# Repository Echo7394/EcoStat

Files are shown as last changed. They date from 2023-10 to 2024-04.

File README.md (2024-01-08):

# EcoStat
<p>
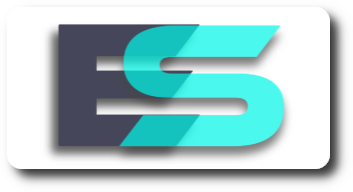
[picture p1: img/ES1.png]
  

EcoStat is an open-source thermostat control system built using the Seed Studio Xiao ESP32C3 microcontroller.
It allows you to control heating, cooling, and fan systems using physical buttons and a web-based interface. 
Additionally, it displays temperature and humidity information on an OLED screen. The goal of this project was
to create a cheap, energy saving, open source smart thermostat that doesnt spy on you. So, finally and most 
importantly, EcoStat does not use or collect any kind of telemetry data, at ALL.

**V2 Supports Heating & Cooling automatically with multiple relays and all additional features.
V1 only supports minimal features with two relays, it can be used for cooling as well. V1 requires you 
to manually move the wire from heating to cooling seasonally, V1 simply offers a cheaper
version of the project.**

I put a lot of soul into this project, and more importantly the desire to keep it free, open source, and unintrusive.
So if you enjoy it, please consider buying me a coffee! <a href="https://cash.app/$seripsirhc">**Donate :)**</a>

</p>
<p float="left">
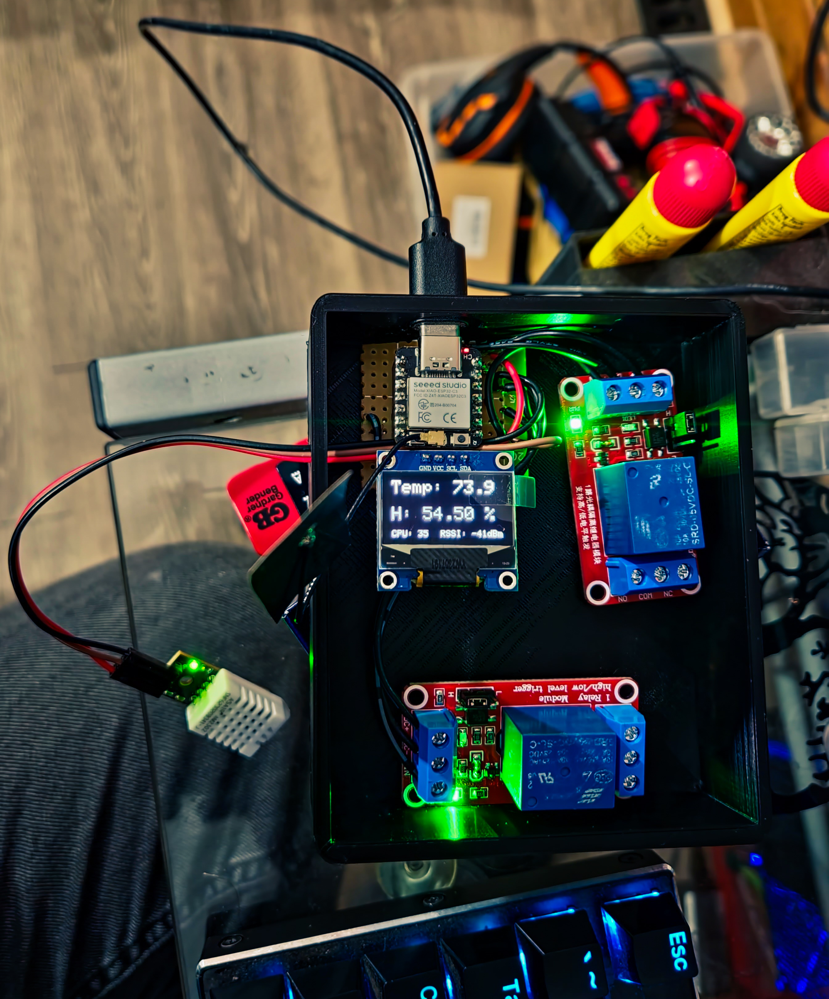
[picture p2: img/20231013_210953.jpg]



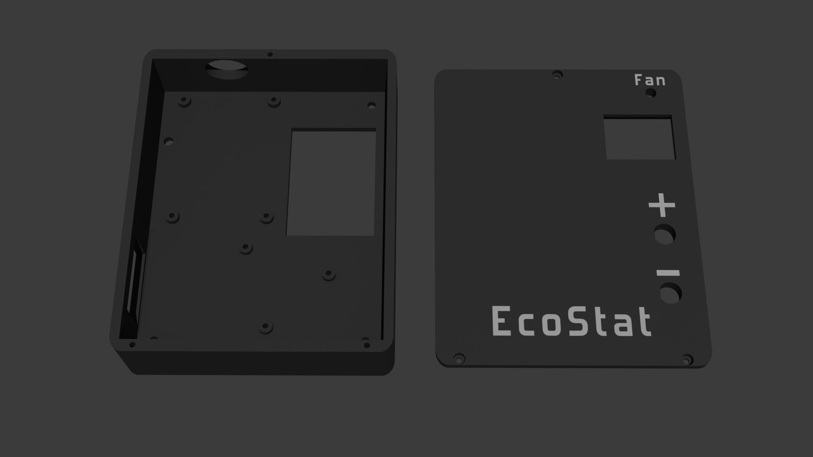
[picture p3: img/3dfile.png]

</p>

**Features:**
<ul>
<p>
<li>Energy efficient HVAC control using timing based logic and hysteresis.</li>
<li>Web-based interface for remote control.</li>
<li>Real-time temperature and humidity display.</li>
<li>Physical buttons for normal offline control.</li>
<li>Mode selection (Heating, Cooling, Off).</li>
<li>Independent Fan control (circulating fan).</li>
<li>Wi-Fi setup using a captive portal.</li>
</p>
</ul>

<hr>

**Hardware Requirements (Total cost approx $45)**

**-Seeed Studio Xiao ESP32C3**

**-Any 128x64 SSD1306 I2C OLED Screen**

**-Two or Three 5V One Channel Relay Modules, I used "HiLetgo 2pcs 5V One Channel Relay Module Relay Switch with OPTO Isolation High Low Level Trigger" from Amazon**
  
**-A DHT22 Sensor, I used a "Gowoops 2pcs DHT22/AM2302 Digital Humidity and Temperature Sensor Module" from Amazon**
  
**-Micro Momentary Button, I used a 4 pin type, you can use anything that fits the mounting hole (6mm or less).**
<hr>

**Software Dependencies**
<p>
	
khoih-prog/ESP_WifiManager@^1.12.1
	
adafruit/DHT sensor library@^1.4.4

adafruit/Adafruit SSD1306@^2.5.7

https://github.com/me-no-dev/ESPAsyncWebServer.git (Must change AsyncWebSocket.cpp: "return IPAddress(0U)"; to "return IPAddress((uint32_t)0U)" )

adafruit/Adafruit Unified Sensor@^1.1.13

</p>
<hr>

**Configuration**
<ul>
<li>Set your desired username and password for web-based authentication using http_username and http_password (default is blank user, with pass: 13371337).</li>
<li>Connect the relay modules and physical buttons to the specified pins as defined in the code.</li>
<li>Install neccessary libraries</li>
<li>Compile/Build</li>
<li>Upload the code to your ESP32C3 device.</li>
<li>Uncomment Serial.begin & Open the serial monitor for debugging (optional).</li>
<li>Access the EcoStat web interface by connecting to the Wi-Fi network "EcoStat-Setup" and visiting the IP address assigned to your device.</li>
<li>Use the web interface to control heating, cooling, fan, and set the target temperature.</li>
</ul>
<hr>

**Button Controls**
<ul>
<li>BUTTON_FAN: Toggle the fan on and off.</li>
<li>BUTTON_MODE: Switch between Heating, Cooling, and Off modes.</li>
<li>BUTTON_PIN0 and BUTTON_PIN1: Increase and decrease the target temperature.</li>
</ul>
<hr>
<p>
The screen displays Temperature, Humidity, MCU Temp, and Wifi Signal Strength.
Buttons toggle temperature up & down by one degree at a time.
The "Heat" relay does not trigger until the current temperature is 2 degrees lower than the target temperature and it has been more than 120 seconds to prevent excessive
toggling and save energy / gas / LP.
The web page also provides the option to trigger the "Fan" relay seperately for air circulation without climate control.</p>
<hr>

Detailed description of the goals of this project and a summary of exactly what the code does:

1. It includes various libraries for Wi-Fi management, sensor readings (DHT22), OLED display control, and web server functionality.
2. It defines pins and addresses for the OLED display, DHT22 sensor, buttons, and relays.
3. It sets up Wi-Fi using the ESPAsyncWiFiManager library, allowing users to configure the network credentials via a captive portal.
4. It initializes the OLED display, creates a web server on port 80, and defines routes for controlling the thermostat remotely.
5. It handles HTTP GET requests for increasing/decreasing the target temperature, turning the fan on/off, and changing the operating mode (heating, cooling, or off).
6. It defines functions for reading the temperature, changing the mode, and updating the OLED display with current status.
7. It sets up interrupt handlers for physical buttons to change the target temperature, mode, or fan status.
8. The main loop continuously reads temperature and humidity from the DHT22 sensor and updates the OLED display.
9. Depending on the operating mode (heating or cooling), it controls relays to turn on/off the heating or cooling system to maintain the desired temperature.

Overall, this code creates a thermostat system with remote control capabilities, allowing users to adjust the target temperature, mode, and fan status through a web interface. It also displays current temperature and humidity on an OLED screen. The system can operate in heating or cooling mode based on the target temperature, and it provides visual feedback on the OLED screen for the user. The physical buttons provide additional control and feedback for users without accessing the web interface. No unnecessary data is collected or transmitted by the device, and no personal data is transmitted outside of your LAN.

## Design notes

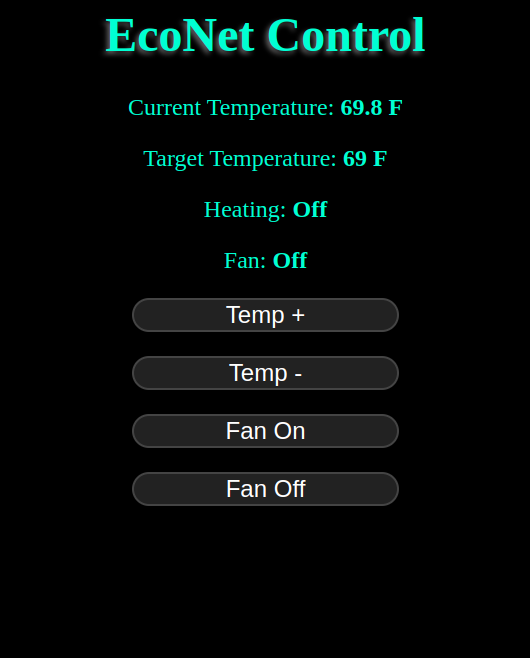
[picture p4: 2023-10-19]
img/EcoNet.png

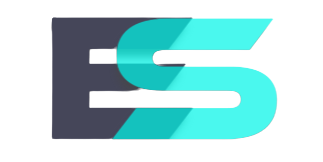
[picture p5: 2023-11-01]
img/blah22-removebg-preview.png

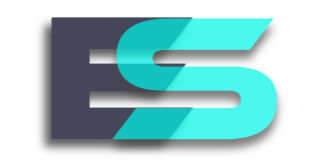
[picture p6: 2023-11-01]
img/blah22.png

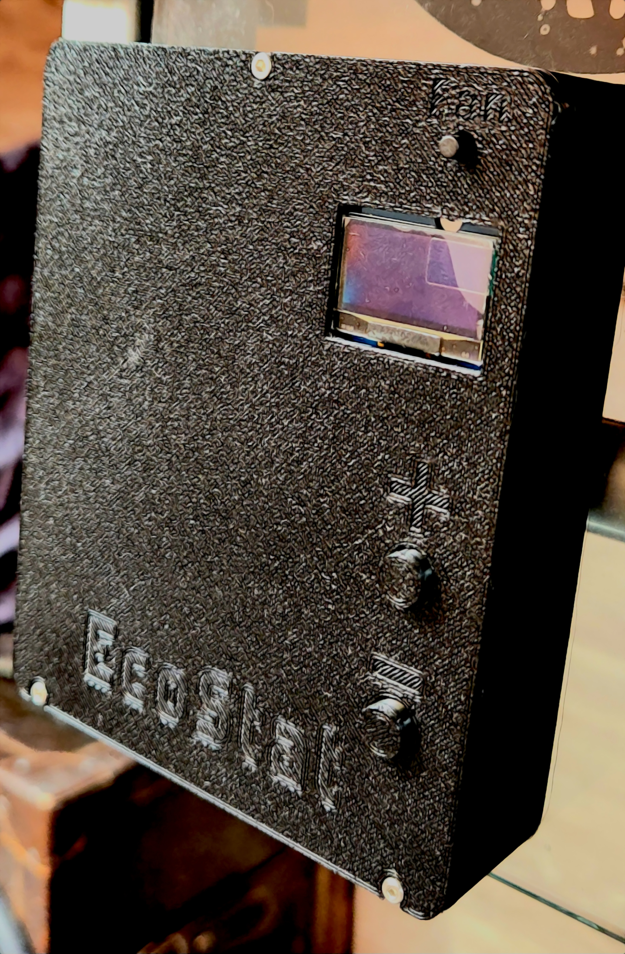
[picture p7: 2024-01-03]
img/esupdate.jpg

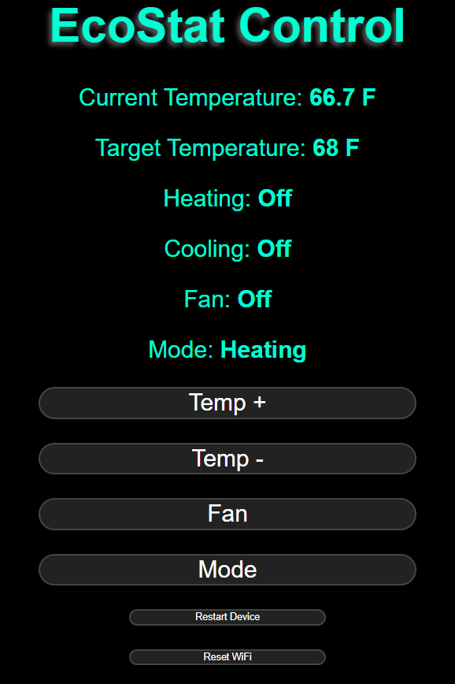
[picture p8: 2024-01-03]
img/esss.png

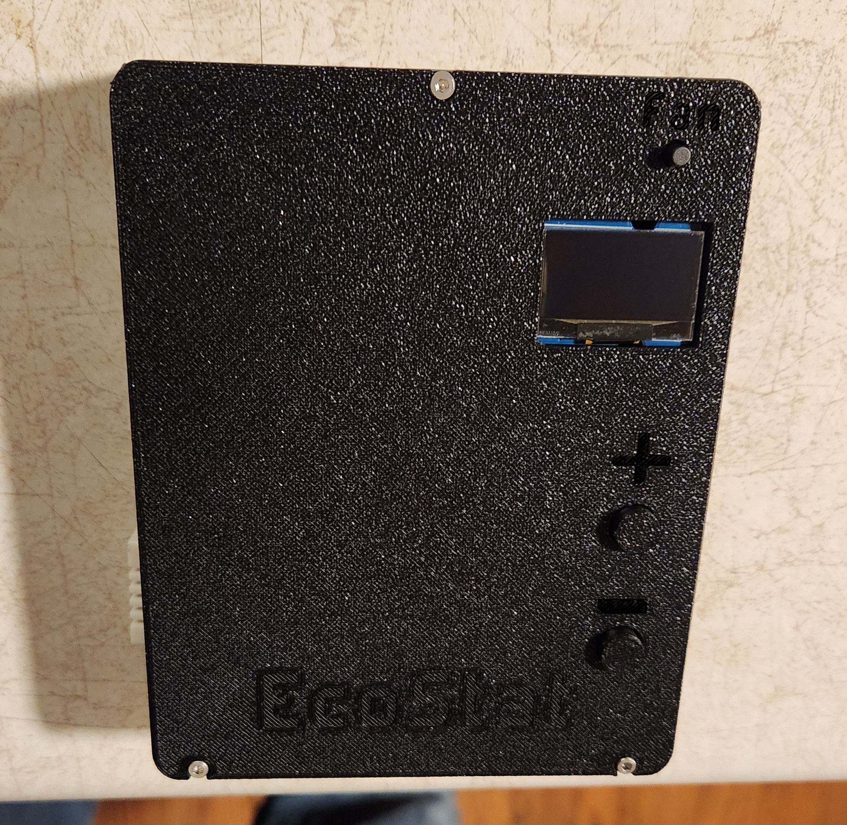
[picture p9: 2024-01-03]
img/ESN1.jpg

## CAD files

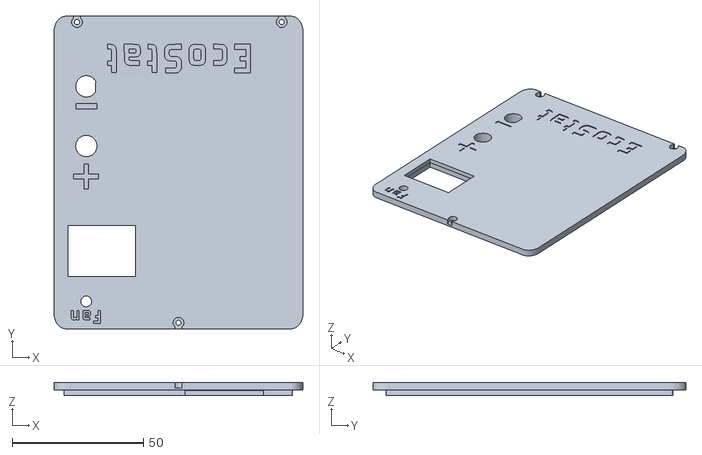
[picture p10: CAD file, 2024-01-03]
Case_Models/EcoStatV2-ecostatlid.stl
94.7 x 118.9 x 5.11

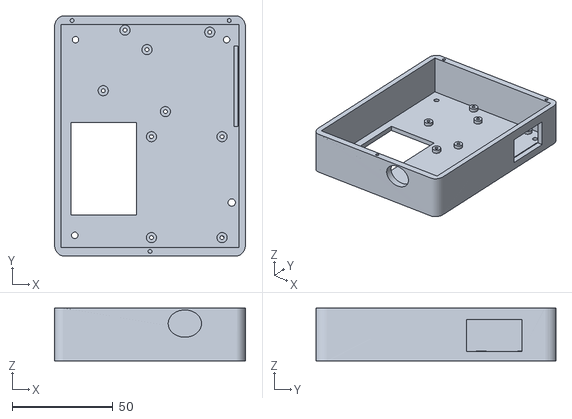
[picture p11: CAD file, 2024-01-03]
Case_Models/EcoStatV2-ecostatcase.stl
94.7 x 118.9 x 26.2

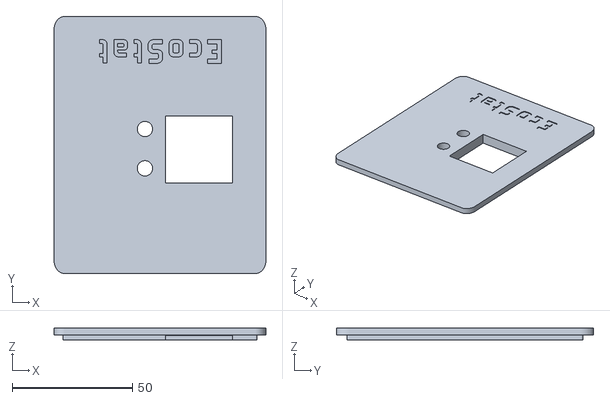
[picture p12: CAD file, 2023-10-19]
Case_Models/microstatlid.stl
88.2 x 107.0 x 5.11

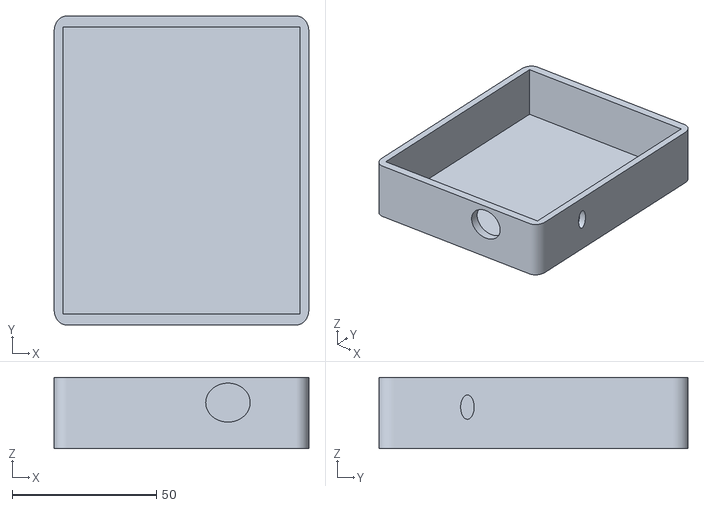
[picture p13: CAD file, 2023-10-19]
Case_Models/microstatcase.stl
88.2 x 107.0 x 24.8

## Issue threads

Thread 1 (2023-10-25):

Seeed Studio Contributor Program

MatthewJeffson, 2023-10-25:
Hi Chris!
It is nice to meet you. I'm Matthew from Seeed Studio and I'm responsible for our little program called "[Contributor Program](https://github.com/orgs/Seeed-Studio/projects/6/views/1?pane=issue&itemId=30957479)". Your project here is so interested and very attached to our recent theme: Home Assistant.

Hence, may I ask if you are interested redoing this project, by using our products(Grove modules)? And let it be able to be controlled and viewed the data on Home Assistant devices?
Here is a reference: [XIAO ESP32C3 connecting with Home Assistant via ESPHome(all ports supported)](https://wiki.seeedstudio.com/XIAO-ESP32C3-for-ESPHome-Support/)

A working demo and wiki contents will be fine. I will create an assignment and assigned to you in our program.
Really looking forward our operation.
Best Regards,
Matthew

Echo7394, 2023-10-25:
I would be extremely happy to create a version of EcoStat that supports Home Assistant using Grove modules. Would you or anyone at Seeed Studio be willing to provide demo hardware (a Xiao ESP32C3 or S3 and Grove Modules) to use for testing and development as well as to create a demo video with?

MatthewJeffson, 2023-10-26:
Hello! Sure I can and happy to ask some hardware for you :)
May we contact with email so we can discuss privately.
Best Regards,
Matthew

Echo7394, 2023-10-26:
Absolutely, my E-Mail is echo7394@protonmail.com

Closed 2024-01-03.

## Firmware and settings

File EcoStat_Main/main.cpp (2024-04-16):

/**************************************************************************************
░█▀▀░█▀▀░█▀█░█▀▀░▀█▀░█▀█░▀█▀     													  
░█▀▀░█░░░█░█░▀▀█░░█░░█▀█░░█░                                                          
░▀▀▀░▀▀▀░▀▀▀░▀▀▀░░▀░░▀░▀░░▀░                                                          
GNU GENERAL PUBLIC LICENSE V3.0                                                       
Made by Echo7394                             
This is the most updated version of the code!!
**************************************************************************************/
#include <ArduinoOTA.h>
#include <DNSServer.h>
#include <ESP_WiFiManager.h>
#include <Wire.h>
#include <DHT.h>
#include <Adafruit_SSD1306.h>
#include <esp_system.h>
#include <ESPAsyncWebServer.h>

#define SCREEN_WIDTH 128
#define SCREEN_HEIGHT 64
#define OLED_RESET -1        // Reset pin (if used)
#define SCREEN_ADDRESS 0x3C  // I2C address for the OLED

Adafruit_SSD1306 display(SCREEN_WIDTH, SCREEN_HEIGHT, &Wire, OLED_RESET);

#define DHT_PIN 20  // Sets the data pin for the DHT22
DHT dht(DHT_PIN, DHT22);

#define BUTTON_FAN 4   // Button to switch fan on and off manually
#define BUTTON_MODE 3  // Button to select "Heating / Cooling / Off"
#define BUTTON_PIN0 8  // Button to raise tempSet
#define BUTTON_PIN1 2  // Button to lower tempSet

#define buzzerPin 5   // trigger pin for piezo buzzer
#define RELAY_PIN 10   // trigger pin for "Heat" relay
#define RELAY_PIN0 5   // trigger pin for "Cooling" relay
#define RELAY_PIN1 21  // trigger pin for "Fan" relay

String ssid = "blank";      // Will store the Wi-Fi SSID from the captive portal
String password = "blank";  // Will store the Wi-Fi password

//IPAddress localIP(192, 168, 0, 201); //Uncomment to set a Static IP for EcoStat
//IPAddress gateway(192, 168, 0, 1);
//IPAddress subnet(255, 255, 255, 0);

AsyncWebServer server(80);  // Web server to port 80 TCP

int tempSet = 68;                        // Initial target temperature in degrees Fahrenheit
const char *http_username = "";          // Change to your desired username
const char *http_password = "199312";  // Change to your desired password

unsigned long lastDebounceTime = 0;       // Momentary switches like to be bouncy
unsigned long debounceDelay = 300;       // These variables will take care of that later
unsigned long modeStatusLastUpdated = 0;  // will be used for timing of displayModeStatus

bool heatingOn = false;  // heating status, starts as false since RELAY_PIN typically starts LOW
bool coolingOn = false;  // cooling status
bool fanisOn = false;    // same as above but for.... the fan relay

bool wifiCredentialsEntered = false;

unsigned long lastDHTPollTime = 0;
const unsigned long dhtPollInterval = 6000;

float celsiusToFahrenheit(float celsius) {  //Converts Celsius to Fahrenheit
  return (celsius * 9.0 / 5.0) + 32.0;
}

int mode = 0;  // 0 for off, 1 for heating, 2 for cooling

void changeMode() {
  mode = (mode + 1) % 3;  // Cycle through modes: 0 -> 1 -> 2 -> 0
  // Turn off heating and cooling when switching modes
  digitalWrite(RELAY_PIN, LOW);
  digitalWrite(RELAY_PIN0, LOW);
}

void displayTempSet(int tempSet) {  // This function gets flashed briefly on the OLED
  display.clearDisplay();           // when the target temp "tempSet" is changed
  display.setTextSize(2);
  display.setTextColor(SSD1306_WHITE);
  display.setCursor(0, 20);
  display.print(F("Target: "));
  display.print(tempSet);
  display.display();
}

void displayFanStatus() {  // Gets flashed to the OLED whenever fanisOn changes
  display.clearDisplay();
  display.setTextSize(2);
  display.setTextColor(SSD1306_WHITE);
  display.setCursor(0, 20);
  if (fanisOn == true) {
    display.print(F("Fan: On"));
  } else {
    display.print(F("Fan: Off"));
  }
  display.display();
}

String modeStatus = "Off";
int modeFan = 0;

void switchFan() {
  modeFan = (modeFan + 1) % 2; // Cycle fan state 0 -> 1 -> 0
  digitalWrite(RELAY_PIN1, modeFan == 1); // Turn on the fan relay when modeFan is 1
  fanisOn = (modeFan == 1);
}

void displayModeStatus(String modeStatus) {  // Gets flashed to the OLED whenever modeStatus changes
  display.clearDisplay();
  display.setTextSize(2);
  display.setTextColor(SSD1306_WHITE);
  display.setCursor(40, 10);
  display.print(F("Mode: "));
  display.setCursor(25,30);
  display.print(modeStatus);
  display.display();

  // Record the time when modeStatus is updated for use later
  modeStatusLastUpdated = millis();
}

void playTone(float frequency, int duration) {
  tone(buzzerPin, frequency);
  delay(duration);
  noTone(buzzerPin);
  delay(100);  // pause between tones
}

// setup function for BUTTON_MODE to increment the value of changeMode
void buttonmodePressed() {
  if (millis() - lastDebounceTime > debounceDelay) {
    changeMode();
    lastDebounceTime = millis();
  }
}

void button0Pressed() {
  if (millis() - lastDebounceTime > debounceDelay) {  // Fancy debounce stuff to make sure a button press = just 1 press
    tempSet += 1;                                     // Increase the target temperature by 1 degree
    lastDebounceTime = millis();
  }
}

void button1Pressed() {
  if (millis() - lastDebounceTime > debounceDelay) {
    tempSet -= 1;  // Increase the target temperature by 1 degree
    lastDebounceTime = millis();
  }
}

void buttonfanPressed() {
  if (millis() - lastDebounceTime > debounceDelay) {
  switchFan();
  lastDebounceTime = millis();
  }
}

void setup() {
  bool setCpuFrequencyMhz(80); // slowwww the CPU frequency down for stability and power consumption
//Serial.begin(115200);  // uncomment this if you need serial output for debugging
  delay(3000);           // Delay because i've heard setup can get skipped sometimes
                         // Do not know if thats true so this may not be neccessary

   playTone(700, 150);
   playTone(1000, 150);

  // Initialize the OLED screen
  if (!display.begin(SSD1306_SWITCHCAPVCC, SCREEN_ADDRESS)) {
    Serial.println(F("SSD1306 allocation failed"));
    for (;;)
      ;
  }

  display.setTextWrap(true);
  display.clearDisplay();  // This just ensures that we start with a clear display
  display.display();       // on the SSD1306 screen

  pinMode(RELAY_PIN, OUTPUT);
  pinMode(RELAY_PIN0, OUTPUT);
  pinMode(RELAY_PIN1, OUTPUT);   // Set Relay trigger pins as outputs, because they are.
  digitalWrite(RELAY_PIN, LOW);  // Ensure the relay is initially off
  digitalWrite(RELAY_PIN0, LOW);
  digitalWrite(RELAY_PIN1, LOW);
  pinMode(BUTTON_PIN0, INPUT_PULLUP);  // Gotta use a pullup for buttons because otherwise
  pinMode(BUTTON_PIN1, INPUT_PULLUP);  // Erwins Cats are going to get involved
  pinMode(BUTTON_FAN, INPUT_PULLUP);

  // display a notification to SSD1306 Screen for user setup if WiFi not attached to SSID
  ESP_WiFiManager wifiManager("EcoStatSetup");
  Serial.println("Waiting for WiFi credentials...");
  display.clearDisplay();
  display.setTextSize(1);
  display.setTextColor(SSD1306_WHITE);
  display.setCursor(15, 0);
  display.print("Connect to WiFi:");
  display.setCursor(28, 15);
  display.print("EcoStatSetup");
  display.setCursor(17, 40);
  display.print("In Your Browser");
  display.setCursor(10, 55);
  display.print("Enter: 192.168.4.1");
  display.display();
  Serial.println(wifiManager.getStoredWiFiPass());
  wifiManager.autoConnect("EcoStatSetup");  // Start a captive portal for the user to enter WiFi Credentials
  ssid = wifiManager.getStoredWiFiSSID();
  password = wifiManager.getStoredWiFiPass();
  wifiManager.setConfigPortalTimeout(300);  // Setup portal timeout in seconds, in case user doesnt setup WiFi
  WiFi.mode(WIFI_STA);

  // Connect to Wi-Fi
  WiFi.begin(ssid, password);
  while (WiFi.status() != WL_CONNECTED) {
    Serial.println("Connecting to WiFi...");
    display.clearDisplay();
    display.setTextSize(2);
    display.setTextColor(SSD1306_WHITE);
    display.setCursor(40, 10);
    display.print(F("WiFi"));  // display to SSD1306
    display.setCursor(5, 30);
    display.print(F("Connecting"));
    display.display();
    delay(1000);
  }
  Serial.println("Connected to WiFi");
  display.clearDisplay();
  display.setTextSize(2);
  display.setTextColor(SSD1306_WHITE);
  display.setCursor(40, 10);
  display.print(F("WiFi"));  // display to SSD1306
  display.setCursor(10, 30);
  display.print(F("Connected"));
  display.display();
  delay(3000);

  ArduinoOTA.begin();
  ArduinoOTA.setHostname("ESP32C3");
  ArduinoOTA.setPassword("ESP32C3");
  dht.begin();

  // Serve a webpage to control features remotely,
  // also added password protection so that you can access it outside of your home LAN
  server.on("/", HTTP_GET, [](AsyncWebServerRequest *request) {
    if (!request->authenticate(http_username, http_password)) {
      return request->requestAuthentication();
    }
    float temperatureC = dht.readTemperature();
    float temperatureF = celsiusToFahrenheit(temperatureC);
    String heatingStatus = heatingOn ? "On" : "Off";  // Determine the state of heatingOn and assign it to heating Status with a variable string
    String fanStatus = fanisOn ? "On" : "Off";        // Same thing but you know... the fan
    String coolingStatus = coolingOn ? "On" : "Off";  // yep
    
    String html = R"webServe(
    <!doctype html>
    <html>
    <body style='text-align: center;font-size: 24px;background-color: #000;color: #00FFD3;@import url('https://fonts.googleapis.com/css2?family=Roboto:wght@300;400;500;900&display=swap');'>
      <head>
        <meta name='viewport' content='width=device-width, initial-scale=1.0'>
        <meta http-equiv='refresh' content='8'>
      </head>
      <h1 style='margin-top: -8px; color: #00FFD3;text-shadow: -3px 3px 5px #5C5C5C;'>EcoStat Control</h1>
      <p>Current Temperature: <strong id='currentTemp'>)webServe" + String(temperatureF, 1) + R"webServe(F</strong></p>
      <p>Target Temperature: <strong><span id='tempSet'>)webServe" + String(tempSet) + R"webServe(</span> F</strong></p>
      <p>Heating: <strong id='heatingStatus'>)webServe" + heatingStatus + R"webServe(</strong></p>
      <p>Cooling: <strong id='coolingStatus'>)webServe" + coolingStatus + R"webServe(</strong></p>
      <p>Fan: <strong id='fanStatus'>)webServe" + fanStatus + R"webServe(</strong></p>
      <p>Mode: <strong id='modeStatus'>)webServe" + (mode == 0 ? "Off" : (mode == 1 ? "Heating" : "Cooling")) + R"webServe(</strong></p>
      <p><button onclick='increaseTemp()'>Temp +</button></p>
      <p><button onclick='decreaseTemp()'>Temp -</button></p>
      <p><button onclick='switchFan()'>Fan</button></p>
      <p><button onclick='changeMode()'>Mode</button></p>
      <p><button class='diff' onclick='restart()'>Restart Device</button></p>
      <p><button class='diff' onclick='reset()'>Reset WiFi</button></p>
      <style>
        button { background-color: #222; color: #fff; border: 2px solid #444; border-radius: 20px; font-size: 24px; width: 25vw; }
        button.diff { background-color: #222; color: #fff; border: 2px solid #444; border-radius: 20px; font-size: 10px; width: 13vw; }
      </style>
      <script>
        function increaseTemp() {
          var xhr = new XMLHttpRequest();
          xhr.open('GET', '/increase', true);
          xhr.send();
          xhr.onload = function () {
            if (xhr.status === 200) {
              var tempSetSpan = document.getElementById('tempSet');
              tempSetSpan.innerText = parseInt(tempSetSpan.innerText) + 1;
            }
          };
        }
        function decreaseTemp() {
          var xhr = new XMLHttpRequest();
          xhr.open('GET', '/decrease', true);
          xhr.send();
          xhr.onload = function () {
            if (xhr.status === 200) {
              var tempSetSpan = document.getElementById('tempSet');
              tempSetSpan.innerText = parseInt(tempSetSpan.innerText) - 1;
            }
          };
        }
        function switchFan() {
          var xhr = new XMLHttpRequest();
          xhr.open('GET', '/fanSwitch', true);
          xhr.send();
          xhr.onload = function () {
            if (xhr.status === 200) {
              var fanStatusVal = document.getElementById('fanStatus');
              fanStatusVal.innerText = (fanStatusVal.innerText === 'On') ? 'Off' : 'On';
            }
          };
        }
        function changeMode() {
          var xhr = new XMLHttpRequest();
          xhr.open('GET', '/changeMode', true);
          xhr.send();
          xhr.onload = function () {
            if (xhr.status === 200) {
              var modeStatus = document.getElementById('modeStatus');
              modeStatus.innerText = xhr.responseText;  // Update the mode status based on the server's response
            }
          };
        }
        function restart() {
          var xhr = new XMLHttpRequest();
          xhr.open('GET', '/restart', true);
          xhr.send();
          xhr.onload = function () {
            if (xhr.status === 200) {
              alert('Device is restarting.');
            } else {
              alert('Failed to restart the device.');
            }
          };
        }
        function reset() {
          var xhr = new XMLHttpRequest();
          xhr.open('GET', '/reset', true);
          xhr.send();
          xhr.onload = function () {
            if (xhr.status === 200) {
              alert('Device is clearing WiFi Settings');
            } else {
              alert('Failed to reset.');
            }
          };
        }
      </script>
    </body>
    </html>
    )webServe";
    request->send(200, "text/html", html);
  });

  server.on("/increase", HTTP_GET, [](AsyncWebServerRequest *request) {  //comments comments so many comments....
    if (!request->authenticate(http_username, http_password)) {
      return request->requestAuthentication();
    }
    tempSet += 1.0;  // Increase the target temperature by 1 degree
    request->send(200, "text/plain", "Increased target temperature by 1 degree.");
  });

  server.on("/decrease", HTTP_GET, [](AsyncWebServerRequest *request) {
    if (!request->authenticate(http_username, http_password)) {
      return request->requestAuthentication();
    }
    tempSet -= 1.0;  // Decrease the target temperature by 1 degree
    request->send(200, "text/plain", "Decreased target temperature by 1 degree.");
  });
  server.on("/fanSwitch", HTTP_GET, [](AsyncWebServerRequest *request) {
  if (!request->authenticate(http_username, http_password)) {
    return request->requestAuthentication();
  }
  switchFan();
  request->send(200, "text/plain", "Fan state switched.");
  });
  server.on("/changeMode", HTTP_GET, [](AsyncWebServerRequest *request) {
  if (!request->authenticate(http_username, http_password)) {
    return request->requestAuthentication();
  }
  changeMode();
  String modeString = (mode == 0 ? "Off" : (mode == 1 ? "Heating" : "Cooling"));
  request->send(200, "text/plain", modeString);  // Send the current mode as the response
  displayModeStatus(modeString);  // Update and display the new mode on the OLED
  });
  server.on("/restart", HTTP_GET, [](AsyncWebServerRequest *request) {
    if (!request->authenticate(http_username, http_password)) {
      return request->requestAuthentication();
    }
    ESP.restart();
  });
  server.on("/reset", HTTP_GET, [&wifiManager](AsyncWebServerRequest *request) {
    if (!request->authenticate(http_username, http_password)) {
      return request->requestAuthentication();
    }
    wifiManager.resetSettings();
    ESP.restart();
  });

  server.begin();

  attachInterrupt(digitalPinToInterrupt(BUTTON_PIN0), button0Pressed, FALLING);  // Interrupt to detect button press
  attachInterrupt(digitalPinToInterrupt(BUTTON_PIN1), button1Pressed, FALLING);
  attachInterrupt(digitalPinToInterrupt(BUTTON_FAN), buttonfanPressed, FALLING);
  attachInterrupt(digitalPinToInterrupt(BUTTON_MODE), buttonmodePressed, FALLING);
}

void loop() {
  ArduinoOTA.handle();

  static bool previousFanState = fanisOn;
  static float previousTempSet = tempSet;  // Store the value of tempSet
  static unsigned long fanStartTime = 0;   // Variable to store the time when the fan relay was turned on, not currently used since i dont see a need for it yet.
  int tempC = temperatureRead();           // read ESP32C3 device temperature for display later
  

  // Read temperature and humidity
  if (millis() - lastDHTPollTime > dhtPollInterval) {
  float temperatureC = dht.readTemperature();
  float temperatureF = celsiusToFahrenheit(temperatureC);  // converts C to F and assigns it to temperatureF because 'Merica
  float humidity = dht.readHumidity();
  lastDHTPollTime = millis();


  int rssi = WiFi.RSSI();  // Comments are exhausting.... I think you can figure this one out.
  Serial.print("Wi-Fi Signal Strength (RSSI): ");
  Serial.print(rssi);  // Not sure why i didnt just output the function itself though
  Serial.println(" dBm");

  // Check if any reads failed
  if (!isnan(temperatureC) && !isnan(humidity)) {  // Display the temperature in Fahrenheit on the OLED screen
    display.clearDisplay();                        // Clear the OLED first in case anything was left behind
    display.setTextSize(2);
    display.setTextColor(SSD1306_WHITE);
    display.setCursor(0, 0);
    display.print(F("Temp: "));
    display.print(temperatureF, 1);  // Display one decimal place
    display.setCursor(0, 30);
    display.print(F("H: "));
    display.print(humidity);
    display.print(F(" %"));
    display.setTextSize(1);
    display.setCursor(0, 56);
    display.print(F("CPU: "));
    display.print(tempC);
    display.setCursor(56, 56);
    display.print(F("RSSI: "));
    display.print(rssi);
    display.print(F("dBm"));
    display.display();  // Show that sweet sweet information on the OLED

    unsigned long lastFurnaceOffTime = 0;  // Store the last time the furnace was turned off
    unsigned long furnaceDelay = 120000;   // Delay before turning the furnace back on (120,000 ms = 120 seconds)
    unsigned long lastCoolingOffTime = 0;
    unsigned long coolingDelay = 120000;

    // Check if the mode status was updated
    if (millis() - modeStatusLastUpdated < 2000) {
      // Display the updated mode status
      displayModeStatus(String((mode == 0 ? "Off" : (mode == 1 ? "Heating" : "Cooling"))));  // Update and display the new mode
      display.display();
    }

    if (mode == 1) {                       // Heating mode
      if (temperatureF < (tempSet - 2)) {  // Turns on heating if the current sensor temp is 2 deg less than the target temp
        if (millis() - lastFurnaceOffTime >= furnaceDelay) {
          digitalWrite(RELAY_PIN, HIGH);
          heatingOn = true;
        }
      } else {
        if (temperatureF >= tempSet) {
          digitalWrite(RELAY_PIN, LOW);
          lastFurnaceOffTime = millis();
          heatingOn = false;
        }
      }
    } else if (mode == 2) {                // Cooling mode
      if (temperatureF > (tempSet + 3)) {  // Turns on cooling if the current sensor temp is 3 degrees more than the target temp
        if (millis() - lastCoolingOffTime >= coolingDelay) {
          digitalWrite(RELAY_PIN0, HIGH);
          digitalWrite(RELAY_PIN1, HIGH);
          fanisOn = true;
          coolingOn = true;
        }
      } else {
        if (temperatureF <= tempSet) {
          digitalWrite(RELAY_PIN0, LOW);
          digitalWrite(RELAY_PIN1, LOW);
          lastCoolingOffTime = millis();
          fanisOn = false;
          coolingOn = false;
        }
      }
    } else if (mode == 0) {
      digitalWrite(RELAY_PIN0, LOW);
      coolingOn = false;
      digitalWrite(RELAY_PIN1, LOW);
      fanisOn = false;
      digitalWrite(RELAY_PIN, LOW);
      heatingOn = false;
    }
  } else {
    //Errror handling if DHT22 Sensor fails or any other logic fails
    display.clearDisplay();  // Clear the OLED first in case anything was left behind
    display.setTextSize(2);
    display.setTextColor(SSD1306_WHITE);
    display.setCursor(0, 0);
    display.print(F("Error: Failure"));
    display.display();
    Serial.println(F("Sum Ting Wong"));
    playTone(2000, 500);
  }
  }
  if (tempSet != previousTempSet) {  
          Serial.print(F("Target Temperature: "));
          Serial.print(tempSet, 1);
          Serial.println(F(" °F"));

          displayTempSet(tempSet);
          previousTempSet = tempSet;
        }

  if (fanisOn != previousFanState) {
    displayFanStatus();
    previousFanState = fanisOn;
  }
  delay(500);
}

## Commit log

2023-10-19 Added 3d model files
    [microstatcase.stl, microstatlid.stl]
2023-10-19 Made Fan: on the webserver update with live values
2023-10-27 Added fan status and functions for a physical fan button
2023-11-16 Fan toggle on web interface
2024-01-06 Fixed DHT22 polling issue
    [main.cpp]
2024-01-06 Fixed WiFi AP Issue
    [main.cpp]
2024-01-09 Fixed JavaScript issue with displaying modeStatus
    [main.cpp]
2024-04-16 Update main.cpp
    Fixed and altered some of the logic that controls the "Cooling" option as it had been untested previously.
    [main.cpp]
